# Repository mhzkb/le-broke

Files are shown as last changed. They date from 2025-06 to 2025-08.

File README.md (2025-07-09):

silly wacky split-but-not-split adaptation of le chiffre.

mx and choc v1 support
2u or 2x 1u bottom row support

ez to assemble, reversible pcb, face down n!n/pro micro (zmk only!!), requires diodes and 2 6x6 buttons.

WATCH YOUR DIODE ORIENTATION!!! IT MATTERS!

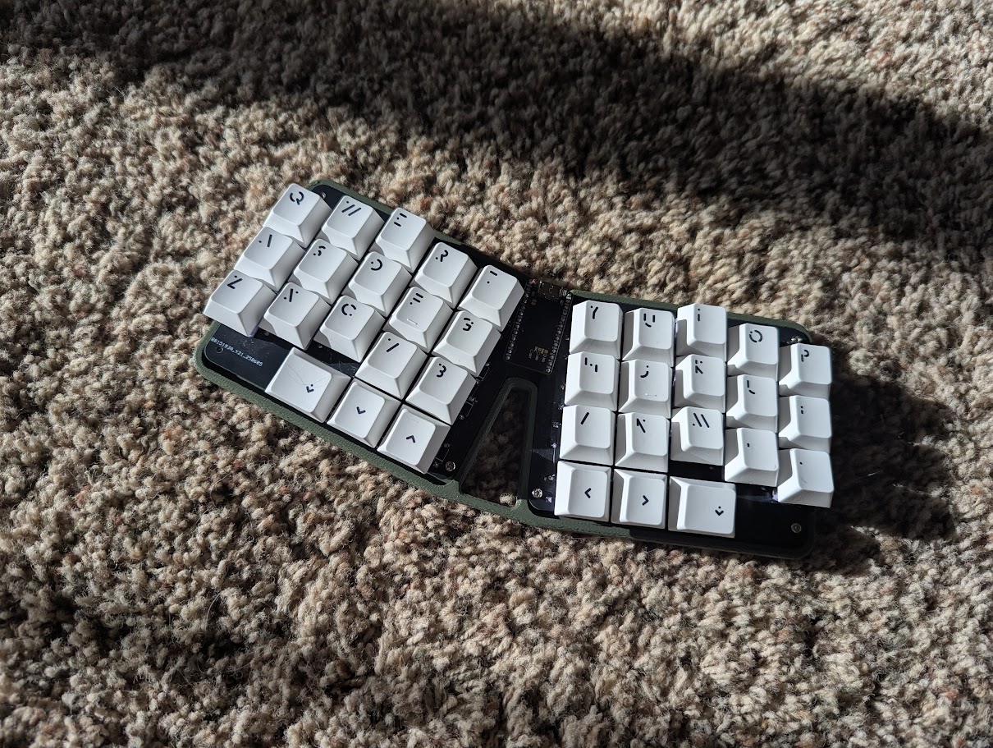
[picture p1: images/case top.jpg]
pretty image of le broke

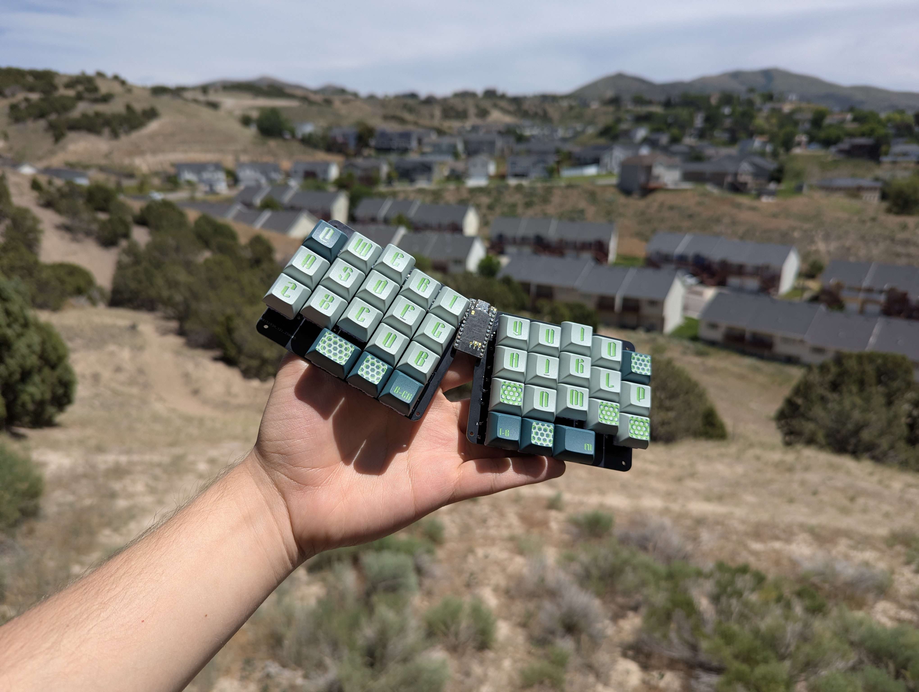
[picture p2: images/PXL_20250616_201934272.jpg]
second pretty image of le broke

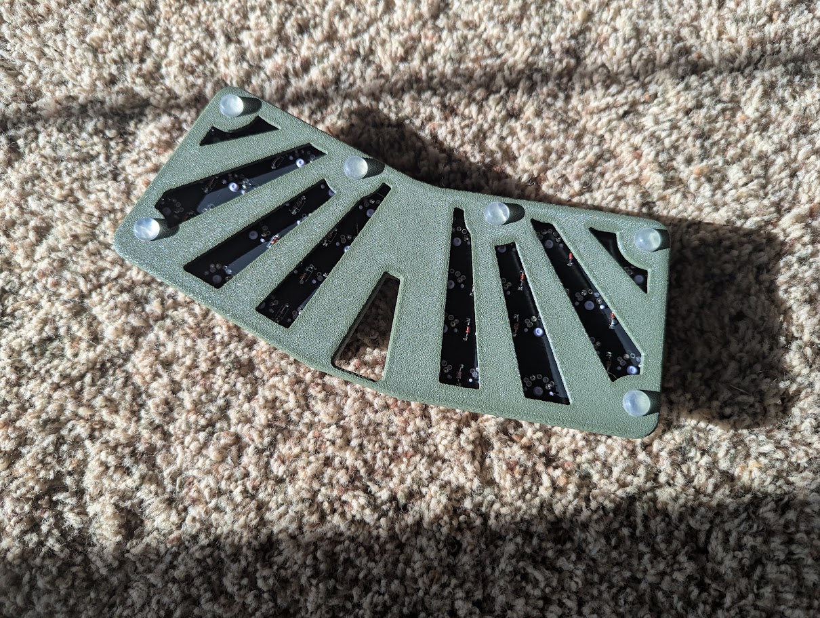
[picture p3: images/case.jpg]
third pretty image of le broke

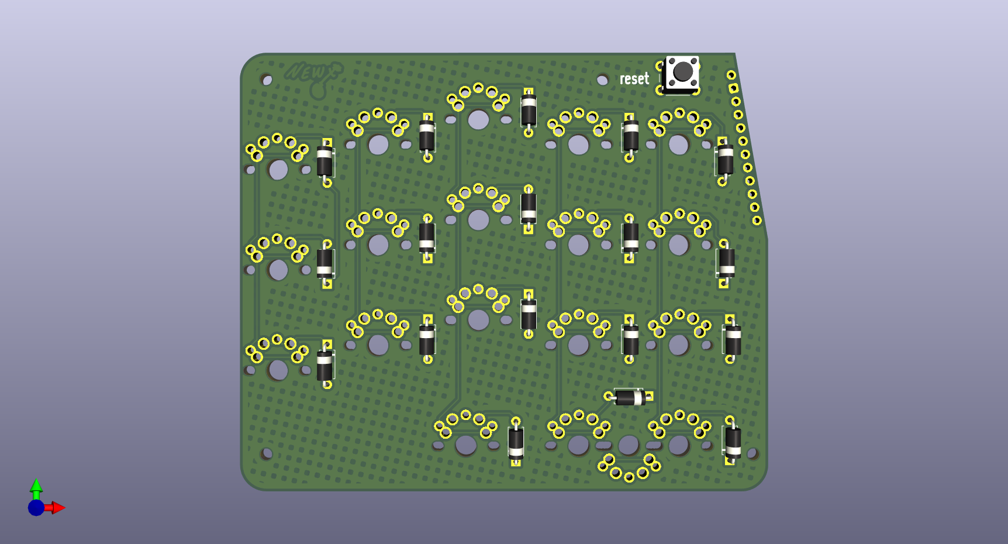
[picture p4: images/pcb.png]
pcb in kicad

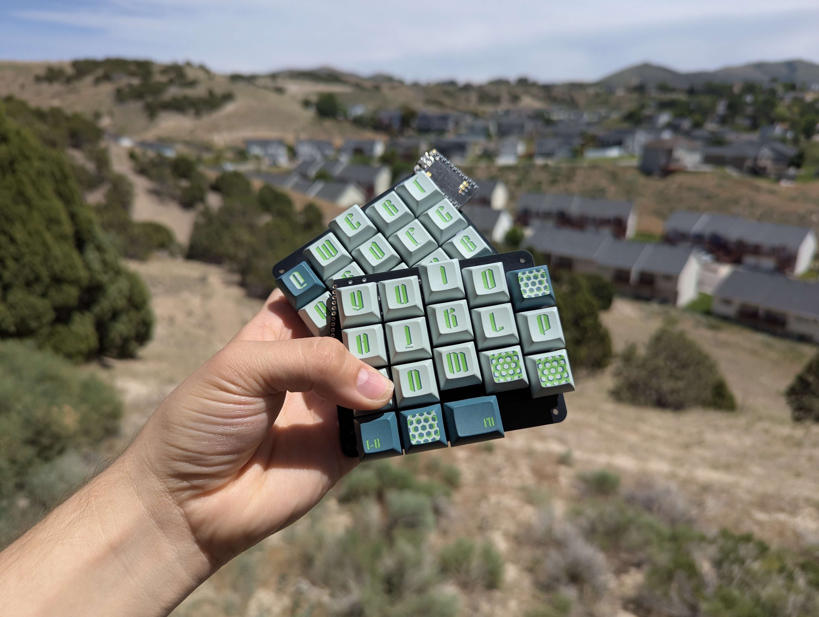
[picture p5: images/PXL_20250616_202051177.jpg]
another pretty image of le broke

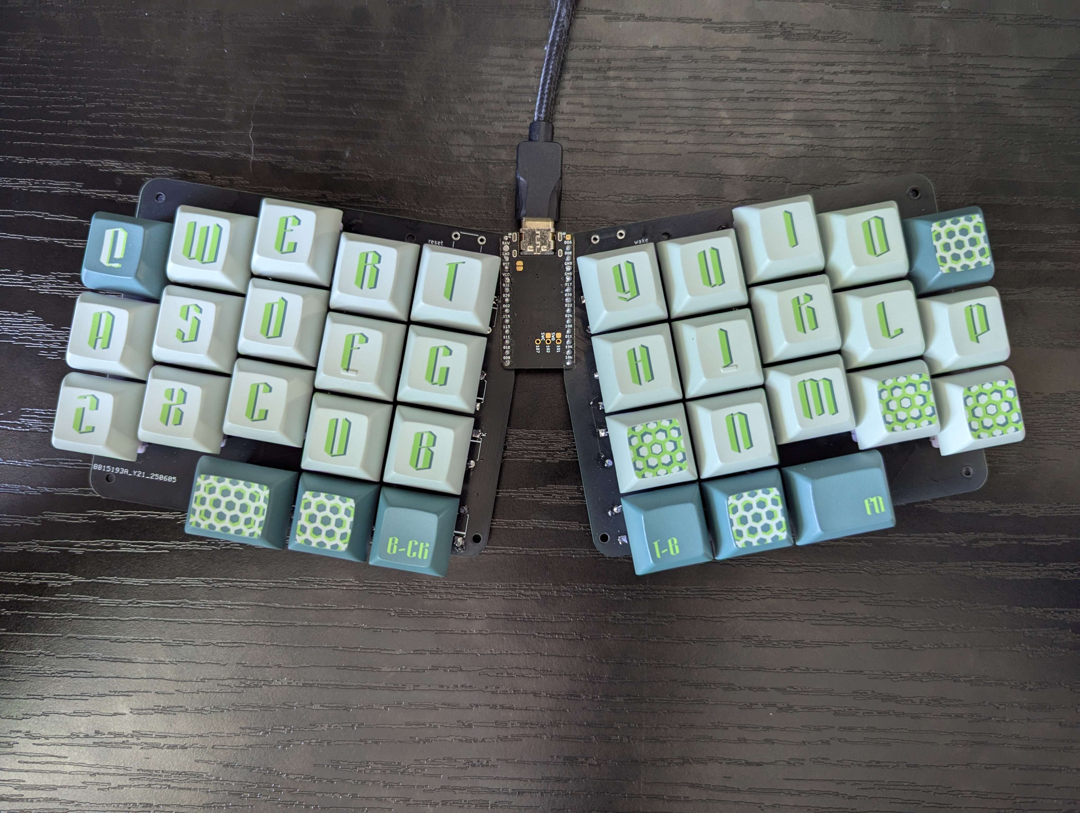
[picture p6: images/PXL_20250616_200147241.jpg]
top

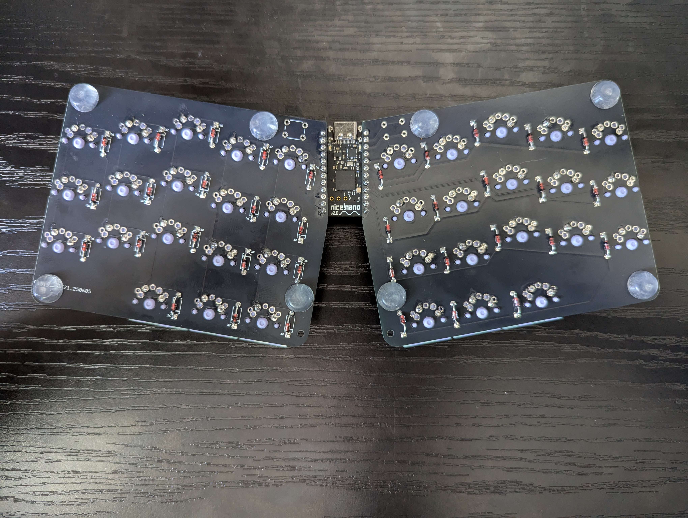
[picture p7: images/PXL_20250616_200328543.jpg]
bottom


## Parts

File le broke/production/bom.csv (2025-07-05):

Designator | Footprint | Quantity | Value | LCSC Part #
D1, D10, D11, D12, D13, D14, D15, D16, D17, D18, D2, D3, D4, D5, D6, D7, D8, D9 | D_A-405_P7.62mm_Horizontal | 18 | D_Small
MX1, MX10, MX11, MX12, MX13, MX14, MX15, MX16, MX17, MX18_2, MX18, MX2, MX3, MX4, MX5, MX6, MX7, MX8, MX9 | SW_MX_1u_rev | 19 | MX_SW_solder
SW1 | SW_PUSH_6mm | 1 | SW_Push

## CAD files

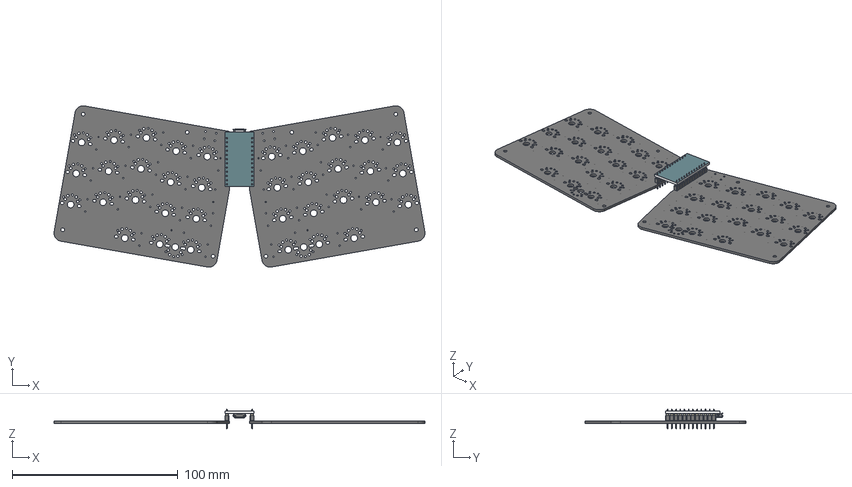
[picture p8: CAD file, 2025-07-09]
le broke/outputs/lebroke_assembly.step
224.1 x 97.4 x 11.9 mm
le broke_PCB x 2
micro board
MICRO_stackable header 12_1 x 2
MICRO_stackable header pin x 24
micro usb shell
micro usb internal
micro usb contact x 5

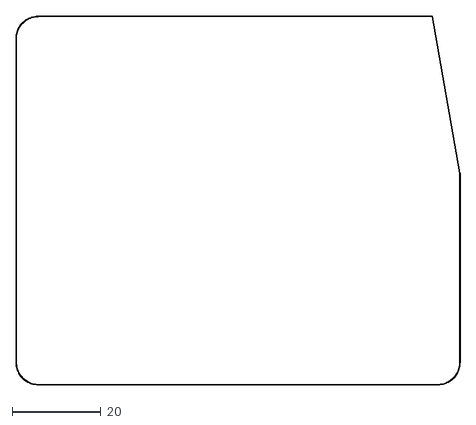
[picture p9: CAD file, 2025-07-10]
le broke/outputs/le broke-Edge_Cuts.dxf
100.0 x 83.0

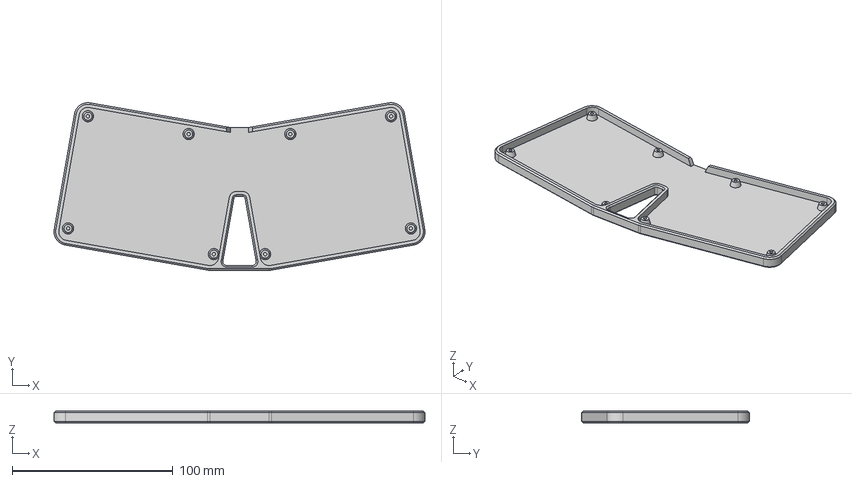
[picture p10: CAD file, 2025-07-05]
MAKE YOUR OWN/case/step/lebroke case.step
231.1 x 104.4 x 7.50 mm

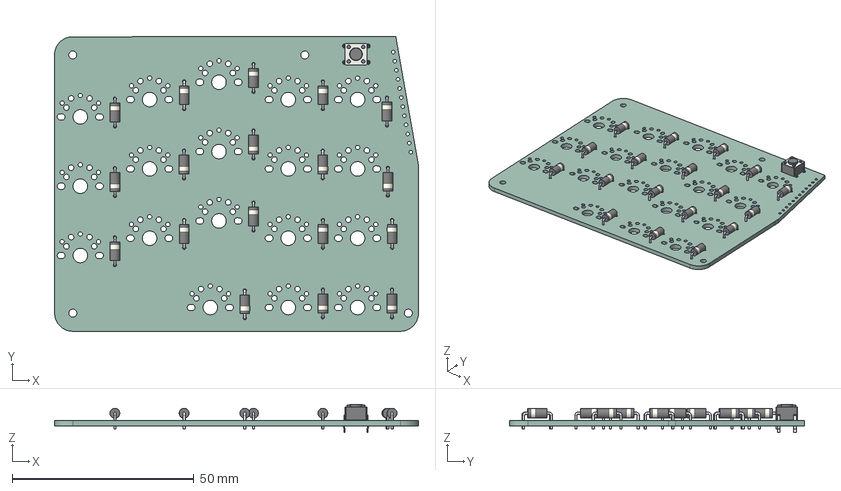
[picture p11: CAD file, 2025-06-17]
MAKE YOUR OWN/source files/le broke pcb.step
100.0 x 81.0 x 7.80 mm
D_A-405_P7.62mm_Horizontal x 18
SW_PUSH_6mm
le broke_PCB

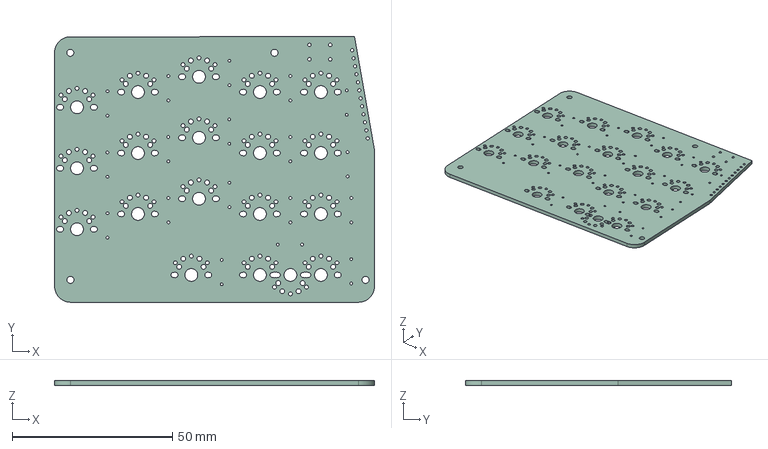
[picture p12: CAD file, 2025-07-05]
le broke/outputs/le broke.step
100.0 x 83.0 x 1.51 mm

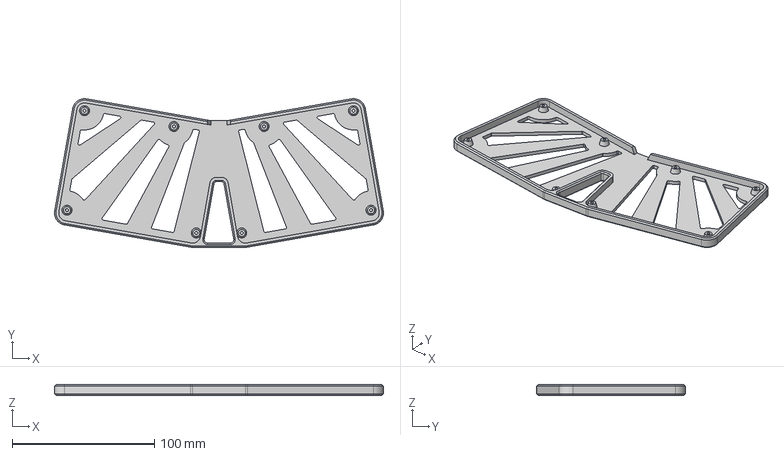
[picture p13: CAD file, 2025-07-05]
MAKE YOUR OWN/case/step/lebroke case cutouts.step
231.1 x 104.4 x 7.50 mm

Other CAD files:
MAKE YOUR OWN/case/step/lebroke case heat inserts.step
MAKE YOUR OWN/case/step/lebroke case cutouts and heat inserts.step
MAKE YOUR OWN/case/stl/lebroke case cutouts and heat inserts.stl
MAKE YOUR OWN/case/stl/lebroke case cutouts.stl
MAKE YOUR OWN/case/stl/lebroke case heat inserts.stl
MAKE YOUR OWN/case/stl/lebroke case.stl

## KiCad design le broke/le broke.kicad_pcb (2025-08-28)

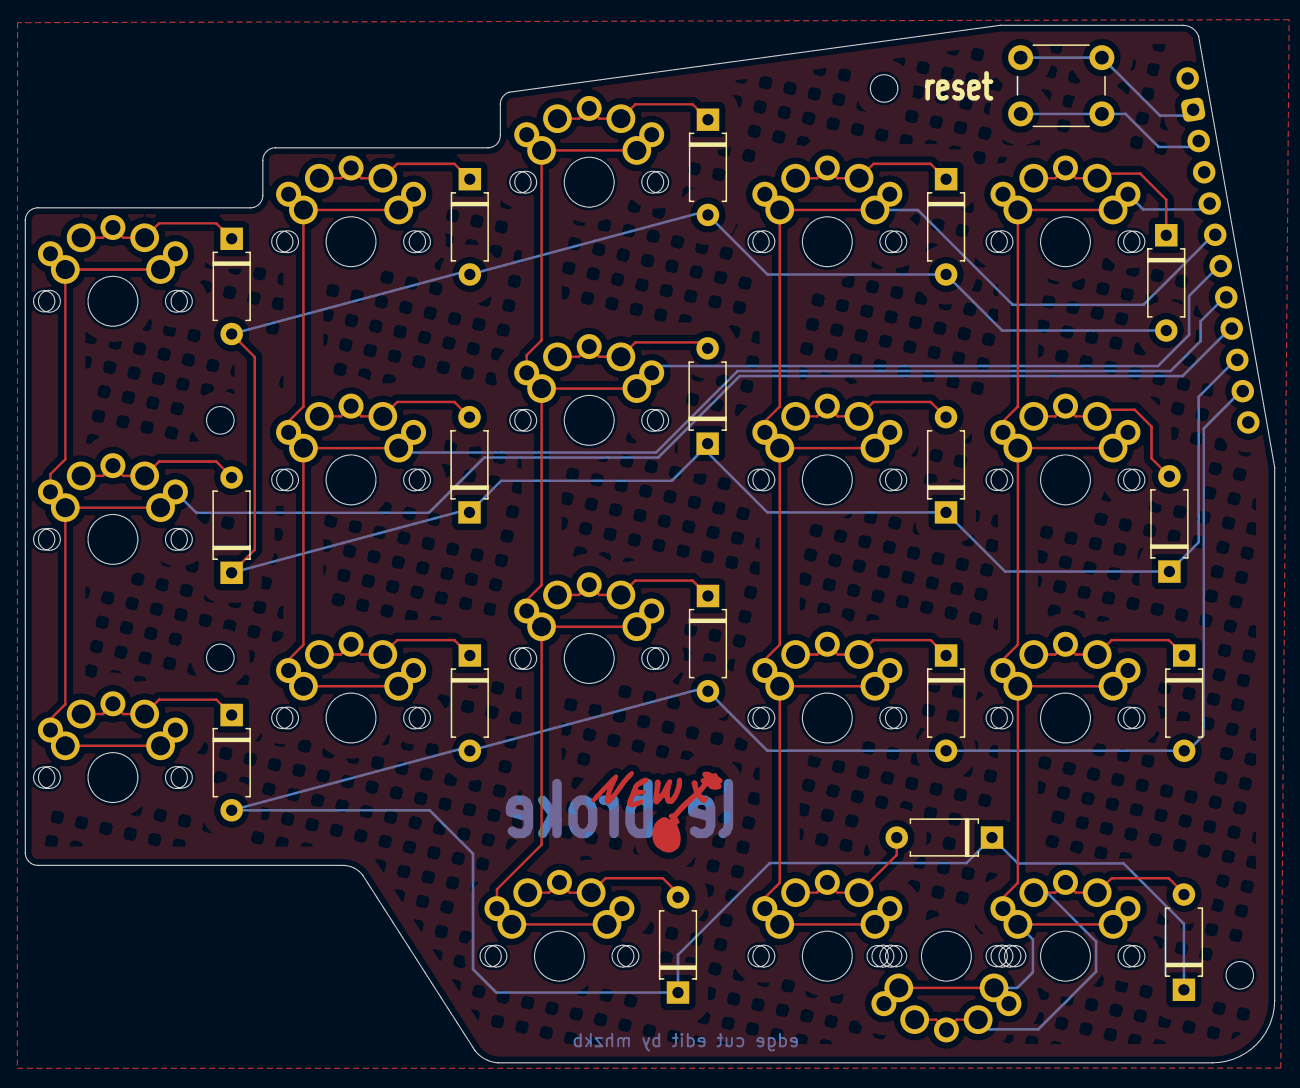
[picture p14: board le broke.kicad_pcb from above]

Board: 2 copper layers, 99.9 x 83.0 mm, 39 parts (1 on the bottom side), 27 nets.

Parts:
D1, D2, D3, D4, D5, D6, D7, D8, D9, D10, D11, D12, D13, D14, D15, D16, D17, D18: D_Small; D_A-405_P7.62mm_Horizontal
MX1, MX2, MX3, MX4, MX5, MX6, MX7, MX8, MX9, MX10, MX11, MX12, MX13, MX14, MX15, MX16, MX17, MX18, MX18#2: MX_SW_solder; SW_MX_1u_rev
SW1: SW_Push; SW_PUSH_6mm
U1: ProMicro; ProMicro_Reversible_Single

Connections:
COL0: MX5.1, MX10.1, MX15.1, U1.21 (B1)
COL1: MX2.1, MX7.1, MX12.1, U1.20 (F7)
COL2: MX1.1, MX6.1, MX11.1, MX16.1, U1.19 (F6)
COL3: MX3.1, MX8.1, MX13.1, MX17.1, U1.18 (F5)
COL4: MX4.1, MX9.1, MX14.1, MX18#2.1, U1.17 (F4)
unnamed: D1.1 (K), MX1.2
unnamed: D2.1 (K), MX2.2
unnamed: D3.1 (K), MX3.2
unnamed: D4.1 (K), MX4.2
unnamed: D5.1 (K), MX5.2
unnamed: D6.2 (A), MX6.2
unnamed: D7.2 (A), MX7.2
unnamed: D8.2 (A), MX8.2
unnamed: D9.2 (A), MX9.2
unnamed: D10.2 (A), MX10.2
unnamed: D11.1 (K), MX11.2
unnamed: D12.1 (K), MX12.2
unnamed: D13.1 (K), MX13.2
unnamed: D14.1 (K), MX14.2
unnamed: D15.1 (K), MX15.2
unnamed: D16.2 (A), MX16.2
unnamed: D17.2 (A), MX17.2
unnamed: D18.2 (A), MX18#2.2
unnamed: SW1.1, U1.14 (GND)
unnamed: SW1.2, U1.15 (RST)
ROW0: D1.2 (A), D2.2 (A), D3.2 (A), D4.2 (A), D5.2 (A), D6.1 (K), D7.1 (K), D8.1 (K), D9.1 (K), D10.1 (K), U1.22 (B3)
ROW1: D11.2 (A), D12.2 (A), D13.2 (A), D14.2 (A), D15.2 (A), D16.1 (K), D17.1 (K), D18.1 (K), U1.23 (B2)

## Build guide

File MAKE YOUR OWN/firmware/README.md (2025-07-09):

Default Keymap:

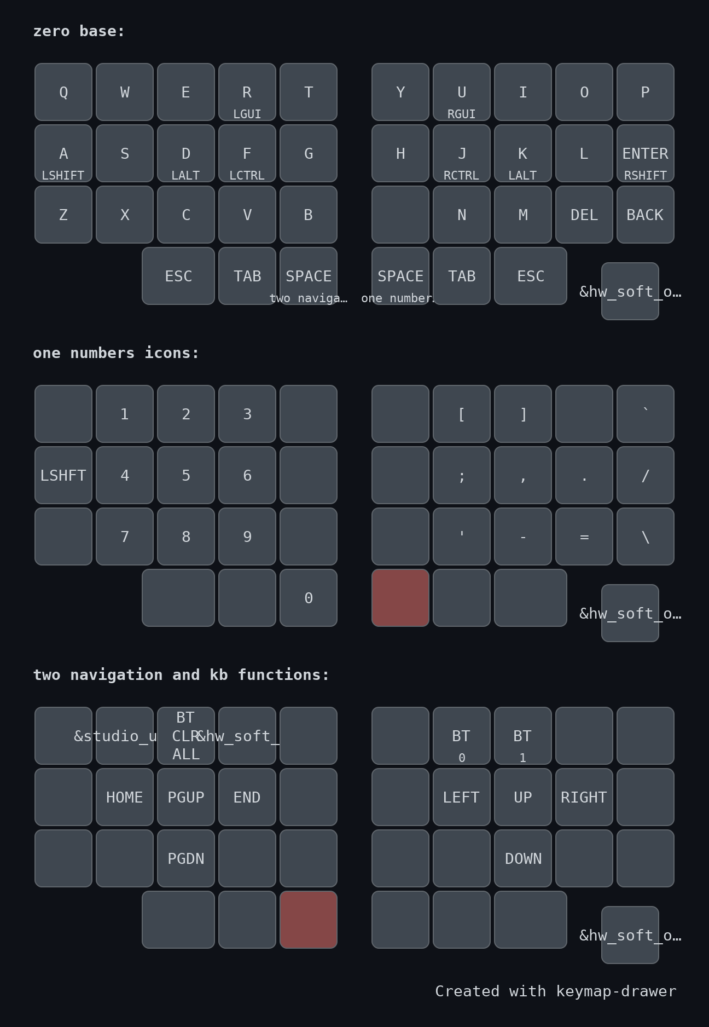
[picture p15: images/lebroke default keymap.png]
pretty image of le broke


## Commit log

2025-06-03 added kicad project
    [le broke.kicad_pcb, le broke.kicad_sch]
2025-06-03 worked
    routing cucked gotta fix
    [le broke.kicad_pcb, le broke.kicad_sch]
2025-06-04 did a lebroke thing idk
    [le broke.kicad_pcb, le broke.step]
2025-06-04 added case DXFs fixed pcb
    [bom.csv, designators.csv, flat.dxf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]
2025-06-11 added 3dp case files
    [good case.stl, silly case.stl]
2025-06-11 renamed cut case files
    [cut 1x any thickness.dxf, cut 1x at least 3mm thick.dxf]
2025-06-17 Create le broke pcb.step
    [le broke pcb.step]
2025-06-26 epic style
    [le broke.kicad_pcb]
2025-07-05 added 2u spacebar support
    [bom.csv, designators.csv, le broke.kicad_pcb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]
2025-07-05 added case files for v2
    [cut 1x any thickness.dxf, cut 1x at least 3mm thick.dxf, good case.stl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]
2025-07-09 added images, updated pcb image
2025-07-09 added STEP of assembled lebroke
    [lebroke_assembly.step]
2025-07-09 added edge cuts
    [le broke-Edge_Cuts.dxf, le broke.step, lebroke_assembly.step]
2025-07-10 Update le broke-Edge_Cuts.dxf
    [le broke-Edge_Cuts.dxf]
2025-07-22 added untested chocV2 pcb and gerbers
    [bom.csv, le broke_chocV2added_untested.kicad_pcb]
2025-08-28 Updated kicad folder
    [bom.csv, designators.csv, le broke-Edge_Cuts.dxf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]
